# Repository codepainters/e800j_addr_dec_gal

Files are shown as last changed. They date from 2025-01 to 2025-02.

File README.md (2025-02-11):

# PROM replacement for Elwro 800 Junior - GAL16V8 variant

Elwro 800 Junior uses two `SN74S474` 512x8 PROMs as IO and memory address decoders. These PROMs are increasingly difficult to obtain (and program), this project provides a `GAL16V8`-based plug-in replacement for both address decoders. 

Note: there is [another version](https://github.com/codepainters/e800j_addr_dec_atf/) using `ATF1502ASL` CPLDs in TQFP-44, if you prefer SMD devices and JTAG programming :) 

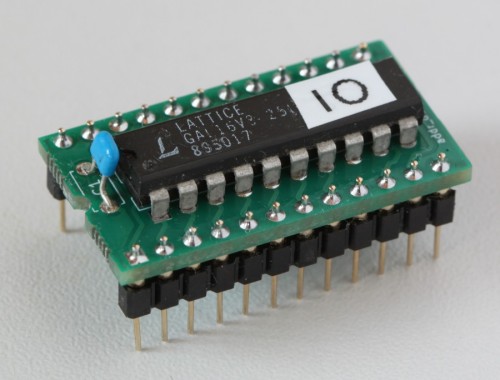
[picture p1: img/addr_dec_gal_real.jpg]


Hardware files:

* [pcb](pcb) - schematic/PCB project in KiCAD 8 format
* PDF schematics - [color](pdf/addr_dec_gal.pdf) and [black&white](pdf/addr_dec_gal_bw.pdf)
* [interactive BOM](addr_dec_gal_ibom.html) file (you have to download it and open locally)
* Gerber files (in a [jlcpcb](https://jlcpcb.com/)-compatible ZIP format):
  * [addr\_dec\_gal.zip](gerbers/addr_dec_gal.zip) - single PCB
  * [addr\_dec\_gal\_panel.zip](gerbers/addr_dec_gal_panel.zip) - two PCBs panelized

PLD sources:

* [io](io) - source and JEDEC file for I/O address decoder
* [mem](mem) - source and JEDEC file for memory address decoder

Both decoders have been verified by comparing them against PROM dumps and tested to ensure they function correctly in the Elwro 800 Junior board.

The source files can be compiled with [galasm](https://github.com/daveho/GALasm) like e.g.:

```
$ galasm io.pld
```

Target `GAL16V8` can be programmed with a `.jed` file using `TL866A` or similar programmer.

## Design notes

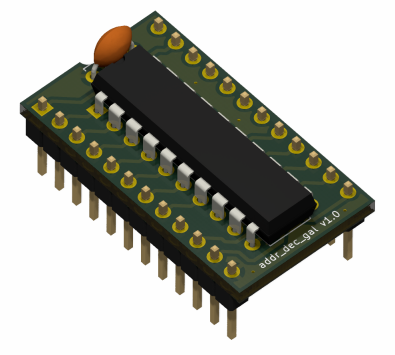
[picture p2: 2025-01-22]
img/addr_dec_gal.png

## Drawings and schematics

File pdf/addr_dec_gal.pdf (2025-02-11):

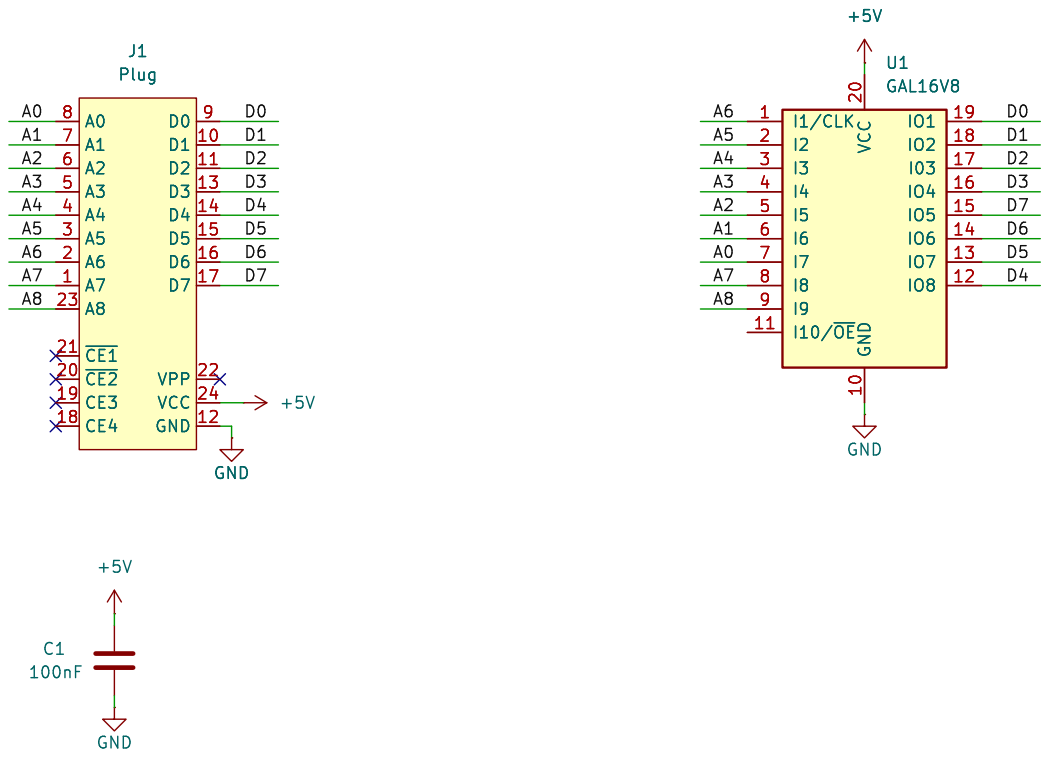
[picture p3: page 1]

Id: 1/1 Title: File: addr_dec_gal.kicad_sch Sheet: / GND

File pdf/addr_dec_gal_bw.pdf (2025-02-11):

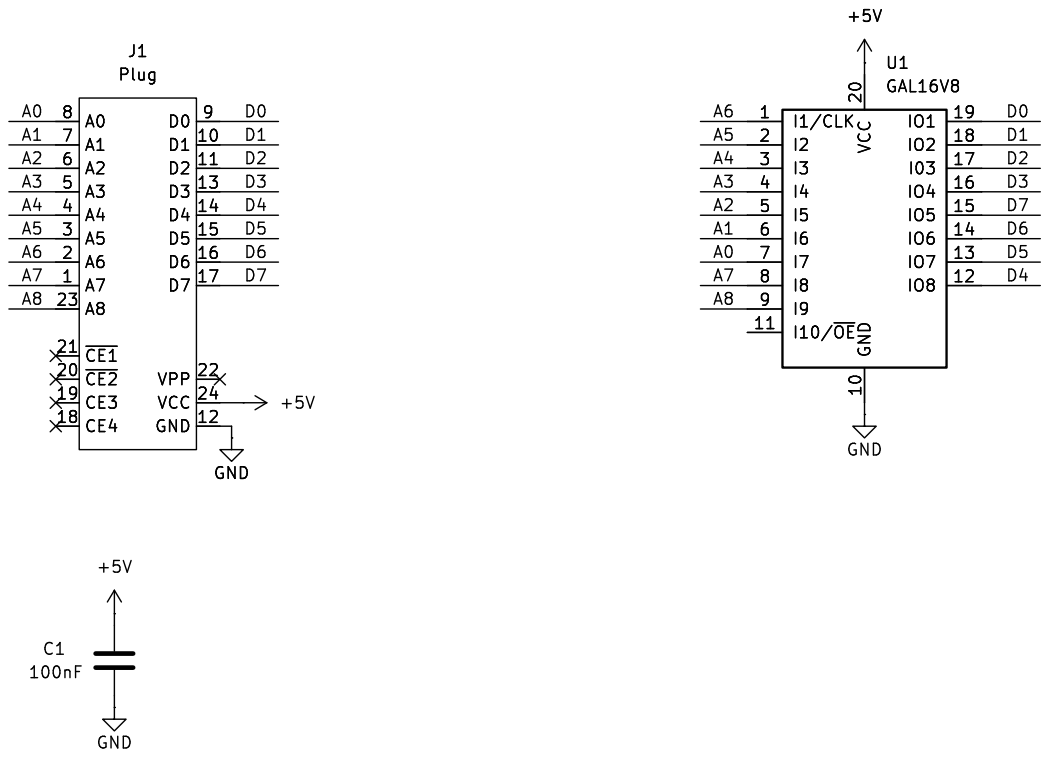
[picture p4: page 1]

Id: 1/1 Title: File: addr_dec_gal.kicad_sch Sheet: / C1

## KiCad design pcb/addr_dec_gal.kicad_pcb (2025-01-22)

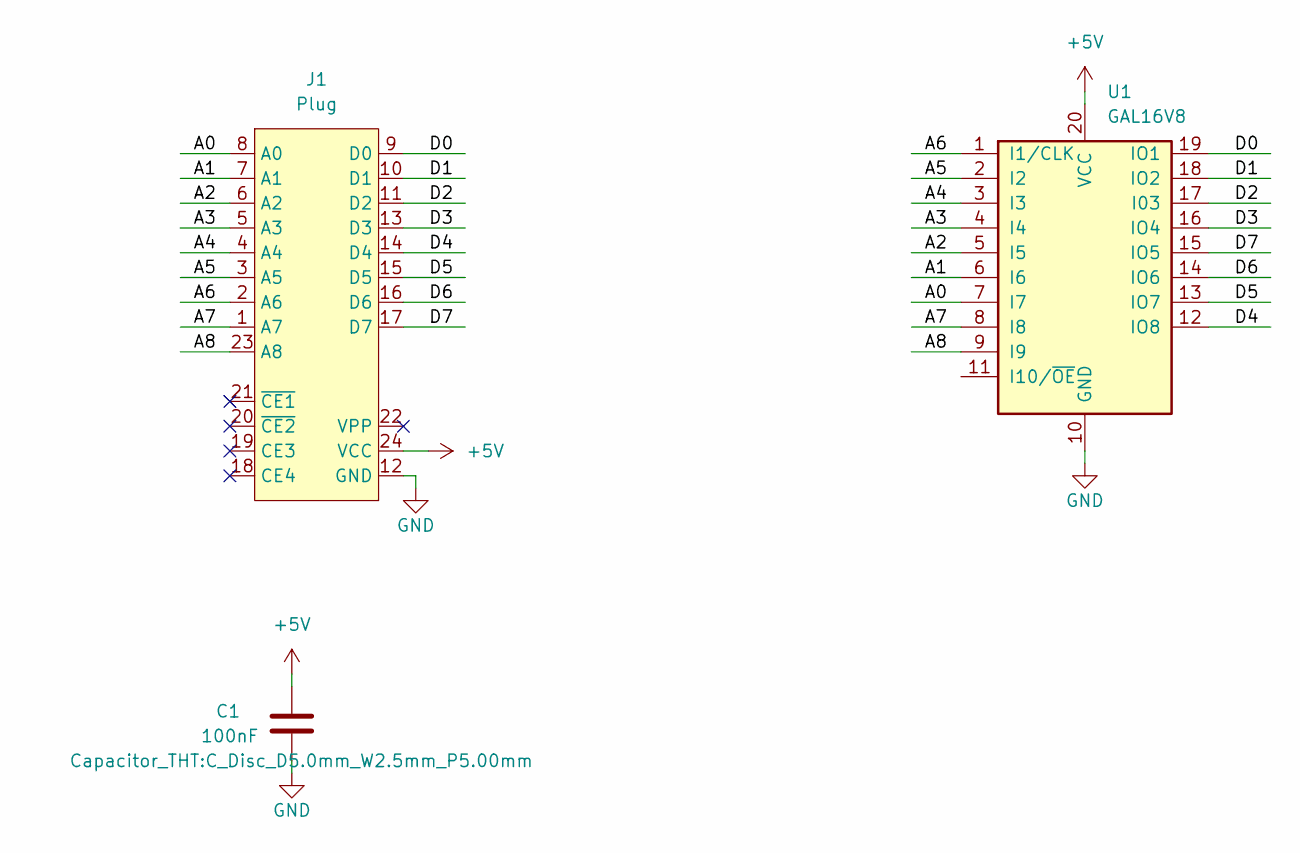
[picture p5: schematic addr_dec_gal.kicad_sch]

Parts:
C1: 100nF; C_Disc_D5.0mm_W2.5mm_P5.00mm
J1: Plug; DIP-24_W15.24mm
U1: GAL16V8; DIP-20_W7.62mm

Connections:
+5V: C1.1, J1.24 (VCC), U1.20 (VCC)
/A0: J1.8 (A0), U1.7 (I7)
/A1: J1.7 (A1), U1.6 (I6)
/A2: J1.6 (A2), U1.5 (I5)
/A3: J1.5 (A3), U1.4 (I4)
/A4: J1.4 (A4), U1.3 (I3)
/A5: J1.3 (A5), U1.2 (I2)
/A6: J1.2 (A6), U1.1 (I1/CLK)
/A7: J1.1 (A7), U1.8 (I8)
/A8: J1.23 (A8), U1.9 (I9)
/D0: J1.9 (D0), U1.19 (IO1)
/D1: J1.10 (D1), U1.18 (IO2)
/D2: J1.11 (D2), U1.17 (I03)
/D3: J1.13 (D3), U1.16 (IO4)
/D4: J1.14 (D4), U1.12 (IO8)
/D5: J1.15 (D5), U1.13 (IO7)
/D6: J1.16 (D6), U1.14 (IO6)
/D7: J1.17 (D7), U1.15 (IO5)
GND: C1.2, J1.12 (GND), U1.10 (GND)

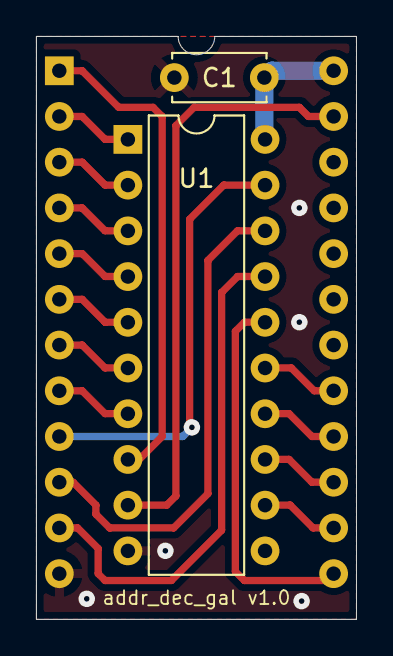
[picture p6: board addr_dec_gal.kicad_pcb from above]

Board: 2 copper layers, 17.8 x 32.4 mm, 3 parts (0 on the bottom side), 19 nets.

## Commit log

2025-01-22 GAL decoder PCB completed
    [addr_dec_gal.kicad_pcb, addr_dec_gal.kicad_sch]
2025-01-22 Added schematic PDF
2025-01-25 sch: comsetic
    [addr_dec_gal.kicad_sch]
2025-02-10 Image of a real PCB.
2025-02-10 Gerbers / iBOM
2025-02-10 Added panelized gerbers
2025-02-11 Added schematic PDFs
